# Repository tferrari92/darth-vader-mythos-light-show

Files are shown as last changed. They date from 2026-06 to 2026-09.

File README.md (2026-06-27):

# Darth Vader Mythos Light Show

An IR-remote-driven light-and-effects show for a Darth Vader Mythos statue, built on an
Arduino Uno. Each track on the remote triggers a choreographed routine synchronized to
music played from a DY-SV5W MP3 module.

The **basic build is 4 RGBW lamps + audio** — that's all you need to run the show. Three
extra effects are **optional** and toggled with feature flags (see
[Configuration](#configuration)): a NeoPixel front strip, smoke (humidifier + fan), and the
lightsaber. With every flag off, the sketch runs the lamps and audio standalone — it does
**not** wait for the ATtiny85 or touch any relays.

## Demo

- 🎥 **Video demo:** _TODO: YouTube link_
- 🖼️ **Build photos:** _TODO: link_

## Architecture

- **Master — Arduino Uno** ([`master/master.ino`](master/master.ino))
  - Drives **4× RGBW lamps** through a **PCA9685** 16-channel PWM driver, using the
    [MultiRGBWLeds](https://github.com/tferrari92/MultiRGBWLeds) library for the animations
    (crossfade, set, side-to-side, spin, flash). *(always on)*
  - Plays audio from a **DY-SV5W** MP3 module (SoftwareSerial). *(always on)*
  - Reads an **IR remote** to select tracks. *(always on)*
  - *Optional:* switches a **smoke** rig (humidifier relay + fan H-bridge) and a
    **lightsaber relay**.
  - *Optional:* sends I²C commands to the ATtiny85 front-strip slave:
    `0xAAAA` → fire animation, `0xBBBB` → blue animation.

- **Slave — ATtiny85** ([`attiny85/attiny85.ino`](attiny85/attiny85.ino)) *(optional — front strip)*
  - Drives a **55-LED WS2812B NeoPixel strip** with FastLED, running a Perlin-noise fire
    effect or a solid blue fill on command. Offloaded to its own MCU so the blocking LED
    timing doesn't disrupt the master's choreography.
  - [`FastLED_RGBW.h`](attiny85/FastLED_RGBW.h) adds RGBW support to FastLED
    (credit: Jim Bumgardner & David Madison).
  - Only needed if you enable the front strip; otherwise you can ignore the `attiny85/` sketch.

## Bill of materials

Build the **Basic** set first; add any of the optional modules later (each maps to a
[feature flag](#configuration)).

### Basic — 4 lamps + audio
- [Arduino Uno (or compatible)](https://a.co/d/03DOTip2)
- [PCA9685 16-channel PWM driver](https://a.co/d/0jiwvAFP)
- [4× RGBW LED lamps (common-anode)](https://a.co/d/08rguR4Z)
- [DY-SV5W Playback Module MP3 Board](https://a.co/d/0iwnKNiH) 
- [3.5mm Aux Cable](https://a.co/d/05ZY8Oyp)
- [Speaker (I used a Bose SoundLink Mini I)](https://a.co/d/0ehsrhri)
- [microSD card](https://a.co/d/0cLakK3m)
- [IR receiver + IR remote](https://a.co/d/0esAqea8)
- [12V powe supply](https://a.co/d/0cVwCTjt)
- [5V power supply](https://a.co/d/0ai2ccZ6)

#### Optional / Quality of life Items
  - [Lever Wire Connectors](https://a.co/d/073DuDCG)
  - [4x 5 Pin Magnetic Pogo Pin Connector](https://a.co/d/08rJCHPg)
  - [12V DC Male + Female Connector](https://a.co/d/08ywx2uR)
  - [USB Extensions Cable](https://a.co/d/0bbNSKzB)
  - [Matte Window Film](https://a.co/d/0bbNSKzB)

### Add-on — Front LED strip
- [Digispark ATtiny85](https://a.co/d/04rXa1Af)
- [3.28ft/1m 60 Pixel RGBW (Warm White) Led Strip](https://a.aliexpress.com/_m0XdlDt) — the sketch drives the first 55 pixels

### Add-on — Back smoke (LED + fan + humidifier)
- [5V Ultrasonic mist / humidifier module](https://a.aliexpress.com/_m0UEqIB)
- [5V L9110 Fan Motor Module](https://a.aliexpress.com/_msmvBKT) 
- LED — _TODO: AliExpress link_
- Relay module — _TODO: AliExpress link_

### Add-on — Lightsaber
- [3V 260mm White Led Filament](https://a.aliexpress.com/_mP3VffN)
- Transparent Acrylic Tube
- UV Resin
- Relay module — _TODO: AliExpress link_

## Wiring



The diagram shows the full wiring including all optional modules — wire only the sections for the modules you're building.

## Dependencies

Install via the Arduino IDE Library Manager (or "Add .ZIP Library"):

**Master (always required):**
- **[MultiRGBWLeds](https://github.com/tferrari92/MultiRGBWLeds)** — companion library for this project (RGBW lamp animations)
- **Adafruit PWM Servo Driver Library** — PCA9685 control
- **DYPlayerArduino** — DY-SV5W MP3 module
- **IRremote — version 3.x** ⚠️

> **Important: use IRremote 3.x, not 4.x.** This sketch uses IRremote's 3.x
> receive API. IRremote 4.x still *compiles* (via a deprecated compatibility
> shim) but **silently fails to decode** — buttons do nothing. In the Library
> Manager, pick a 3.x version (e.g. 3.9.0).

**ATtiny85 front strip (only if `ENABLE_FRONT_STRIP`):**
- **FastLED**

`SoftwareSerial` and `Wire` ship with the Arduino core.

## Configuration

Optional hardware is controlled by feature flags at the top of
[`master/master.ino`](master/master.ino). Arduino has no runtime env vars, so these are
compile-time toggles. They default to **off**, so the basic 4-lamp + audio build works
out of the box.

```cpp
#define ENABLE_FRONT_STRIP 0   // ATtiny85 NeoPixel front strip (I2C slave)
#define ENABLE_SMOKE       0   // Humidifier + fan
#define ENABLE_LIGHTSABER  0   // Lightsaber relay
```

Set a flag to `1` to enable that effect. The flags are wrapped in `#ifndef`, so you can also
override them at build time **without editing the file** (the closest thing to an "env var"):

```bash
# arduino-cli
arduino-cli compile --fqbn arduino:avr:uno master \
  --build-property "build.extra_flags=-DENABLE_SMOKE=1 -DENABLE_LIGHTSABER=1"
```

```ini
; platformio.ini
build_flags = -DENABLE_FRONT_STRIP=1 -DENABLE_SMOKE=1 -DENABLE_LIGHTSABER=1
```

Note: the lamp choreography is timed to the audio, so the small settle delays around the
front-strip commands are preserved even when the strip is disabled — the show stays in sync
in every configuration.

## Build & flash

1. Install the dependencies above.
2. (Optional) Set the [feature flags](#configuration) for any extra hardware you wired up.
3. **Master:** open [`master/master.ino`](master/master.ino), select **Arduino Uno**, upload.
4. **Slave (only if you enabled the front strip):** open
   [`attiny85/attiny85.ino`](attiny85/attiny85.ino), select the ATtiny85 via
   [ATTinyCore](https://github.com/SpenceKonde/ATTinyCore), upload.

## Controls

The IR remote maps each track to a routine (timed to the audio). Effects in *italics*
only fire if their feature flag is enabled. (Button codes are for the bundled NEC remote;
if yours differs, read the HEX over Serial at 9600 and update the cases in `master.ino`.)

| Button | Action |
|---|---|
| **1** | **I Did – Original** |
| **2** | **I Did – Cumbia** |
| **3** | **I Did – Lofi** |
| **4** | **I Did – Metal**  |
| **5** | **For Whom The Bell Tolls** |
| **Power** | Toggle the always-on ambient scene |

## Enclosure

3D-printable enclosure that holds everything together — the STL lives at
[`enclosure/enclosure.stl`](enclosure/enclosure.stl).

## Audio

The audio files live on the DY-SV5W's **microSD card**, numbered in track order:

- `0001 - I Did (Original).mp3`
- `0002 - I Did (Cumbia).mp3`
- `0003 - I Did (Lofi).mp3`
- `0004 - I Did (Metal).mp3`
- `0005 - For Whom The Bell Tolls.mp3` (Epic hallway scene from Rogue One)
- `0006 - KeepAlive.wav` — a low, looping keep-alive tone that plays whenever nothing else is,
  so the audio amp never sees silence and never auto-sleeps

They are **not** committed to this repo.

- ⬇️ [**Download tracks**](https://drive.google.com/drive/folders/14aJys-XmJGN54O0cnzooF6nU0tt411FF?usp=sharing)

## License

[MIT](LICENSE) © Tomas Ferrari

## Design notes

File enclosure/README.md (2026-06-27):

# Enclosure

3D-printable enclosure that houses the electronics for the Darth Vader Mythos light show.

Use this as a rough sketch. Specific meausurements may vary depending on your requirements. But I suggest not going under 120cm x 45cm x 12cm.

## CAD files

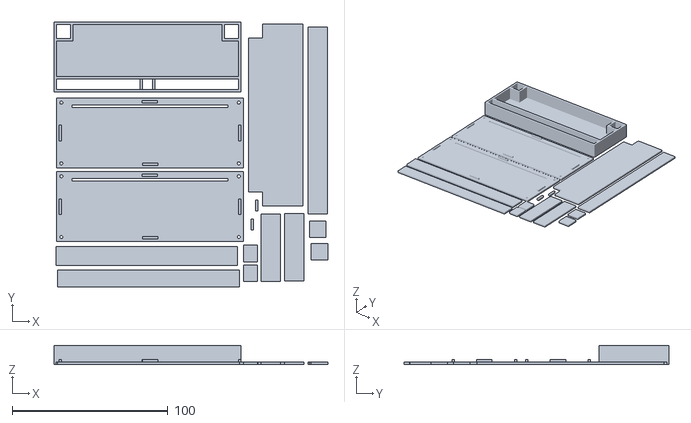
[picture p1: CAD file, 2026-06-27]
enclosure/enclosure.stl
176.0 x 170.0 x 12.4

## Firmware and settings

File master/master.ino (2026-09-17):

#include <Arduino.h>
#include "SoftwareSerial.h"
#include "Wire.h"
#include <MultiRGBWLeds.h>
#include "DYPlayerArduino.h"
#include "IRremote.h"

// ============================================================
//  FEATURE FLAGS
//  ------------------------------------------------------------
//  The basic build is 4 RGBW lamps + audio, which works with
//  every flag below set to 0. Turn on the extra hardware you
//  actually wired up by setting its flag to 1.
//
//  You can either edit the defaults here, OR override them at
//  build time without touching this file (the closest thing to
//  an "env var" on Arduino), e.g. with arduino-cli:
//    --build-property "build.extra_flags=-DENABLE_SMOKE=1"
//  or in platformio.ini:
//    build_flags = -DENABLE_SMOKE=1
// ============================================================
#ifndef ENABLE_FRONT_STRIP
#define ENABLE_FRONT_STRIP 0 // ATtiny85 NeoPixel front strip (I2C slave)
#endif
#ifndef ENABLE_SMOKE
#define ENABLE_SMOKE 0 // Humidifier + fan
#endif
#ifndef ENABLE_LIGHTSABER
#define ENABLE_LIGHTSABER 0 // Lightsaber relay
#endif

// RGBW lamps -- the MultiRGBWLeds library owns the PCA9685 (default 0x40).
MultiRGBWLeds leds;

// MP3 Player -- always required for audio
SoftwareSerial mySerial(3, 11); // RX, TX (MP3 Player)
const int volume = 25;          // Volume level
DY::Player player(&mySerial);

// IR Receiver -- always required
const int receiver = 13;          // Signal Pin of IR receiver to Arduino Digital Pin 13
IRrecv irrecv(receiver);          // Create instance of 'irrecv'
bool ambientOn = false;               // Power button toggles the static ambient scene
unsigned long lastPressMs = 0;        // millis() of the last accepted IR press
const unsigned long debounceMs = 500; // ignore repeat presses within this window

// Audio amp keep-alive: a low, looping tone (track 6 on the SD) plays whenever
// nothing else is, so the amp never sees silence and never auto-sleeps.
const int keepAliveTrack = 6;
unsigned long lastKeepAliveMs = 0;
const unsigned long keepAliveCheckMs = 1000; // how often to re-check play state

// ATtiny I2C Slave Address (front strip)
#define slaveAddress 0x23

// Relay (Humidifier) -- smoke
const int humedifierRelay = 7;

// Relay (Lightsaber)
const int lighsaberRelay = 8;

// Fan -- smoke
const int fanInA = 9;
const int fanInB = 10;
const int speed = 120;

// ------------------------------------------------------------
//  Optional-hardware wrappers
//  These no-op when their feature is disabled, so the show
//  functions below stay readable and the #if guards live here.
// ------------------------------------------------------------

// Send a command to the ATtiny front-strip slave.
// The original protocol included a 500ms settle delay that the
// show timings are tuned around -- we keep it even when the strip
// is disabled so the lamp choreography stays in sync with the audio.
void frontStripSend(uint16_t command)
{
#if ENABLE_FRONT_STRIP
    Wire.beginTransmission(slaveAddress);
    Wire.write(highByte(command));
    Wire.write(lowByte(command));
    Wire.endTransmission();
    Serial.print("Sent command: 0x");
    Serial.println(command, HEX);

    delay(500); // Allow time for the slave to process

    // Request confirmation from ATtiny
    Wire.requestFrom(slaveAddress, 1);
    if (Wire.available())
    {
        byte confirmation = Wire.read();
        Serial.print("Confirmation: 0x");
        Serial.println(confirmation, HEX);
    }
#else
    (void)command;
    delay(500); // Keep choreography in sync with the audio
#endif
}

// Smoke = humidifier + fan, switched on/off together.
void smokeOn()
{
#if ENABLE_SMOKE
    // Turn fan ON
    analogWrite(fanInA, speed); // PWM Speed. 255 is full speed
    digitalWrite(fanInB, LOW);  // Direction
    // Activate humidifier
    digitalWrite(humedifierRelay, HIGH);
#endif
}

void smokeOff()
{
#if ENABLE_SMOKE
    digitalWrite(humedifierRelay, LOW);
    // Turn fan OFF
    digitalWrite(fanInA, LOW);
    digitalWrite(fanInB, LOW);
#endif
}

void saberOn()
{
#if ENABLE_LIGHTSABER
    digitalWrite(lighsaberRelay, HIGH);
#endif
}

void saberOff()
{
#if ENABLE_LIGHTSABER
    digitalWrite(lighsaberRelay, LOW);
#endif
}

// ------------------------------------------------------------
//  Ambient scene
//  The calm resting state the rig falls back to. The Power button
//  snaps to it; finished shows fade up into it.
// ------------------------------------------------------------

// Snap straight to the ambient scene (used by the Power toggle).
void setAmbient()
{
    leds.set(
        LampPosition::FrontLeft, LampColor::White, 1,
        LampPosition::BackLeft, LampColor::Orange, 5,
        LampPosition::FrontRight, LampColor::White, 10,
        LampPosition::BackRight, LampColor::Red, 2);
    ambientOn = true;
}

// Fade up into the ambient scene from dark over durationMs.
void fadeToAmbient(uint16_t durationMs)
{
    leds.resetAllPositions(); // known starting point (off) so the fade is clean
    leds.crossFade(
        LampPosition::FrontLeft, LampColor::White, 0, LampColor::White, 1,
        LampPosition::BackLeft, LampColor::Orange, 0, LampColor::Orange, 5,
        LampPosition::FrontRight, LampColor::White, 0, LampColor::White, 10,
        LampPosition::BackRight, LampColor::Red, 0, LampColor::Red, 2,
        durationMs);
    ambientOn = true;
}

// Called when a light show finishes: hold for a couple of seconds,
// then gently drift back into the ambient scene.
void returnToAmbient()
{
    leds.resetAllPositions(); // clear whatever the show left lit
    delay(500);              // a couple of seconds of darkness after the show
    fadeToAmbient(3000);      // gentle fade-in
}

void setup()
{
    // Terminal
    Serial.begin(9600);

    // MP3 Player
    player.begin();
    player.setVolume(volume);

    // IR Receiver
    irrecv.enableIRIn(); // Start the receiver

    // RGBW lamps. begin() creates/configures the PCA9685 and calls Wire.begin().
    // Each lamp is four PCA9685 channels (0-15) in {R, G, B, W} order.
    const uint8_t backLeft[4] = {4, 5, 6, 7};
    const uint8_t frontLeft[4] = {0, 1, 2, 3};
    const uint8_t frontRight[4] = {12, 13, 14, 15};
    const uint8_t backRight[4] = {8, 9, 10, 11};
    leds.begin(backLeft, frontLeft, frontRight, backRight);

#if ENABLE_SMOKE
    // Relay (Humidifier) + Fan
    pinMode(humedifierRelay, OUTPUT);
    pinMode(fanInA, OUTPUT);
    pinMode(fanInB, OUTPUT);
#endif

#if ENABLE_LIGHTSABER
    // Relay (Lightsaber)
    pinMode(lighsaberRelay, OUTPUT);
#endif

#if ENABLE_FRONT_STRIP
    // Check if ATtiny slave is available. Keep retrying until it is found.
    while (true)
    {
        Wire.beginTransmission(slaveAddress);
        byte busStatus = Wire.endTransmission();

        if (busStatus == 0)
        {
            Serial.println("Slave found.");
            break; // Exit the loop and continue execution
        }

        Serial.println("Slave not found. Retrying...");
        delay(1000); // Wait 1 second before retrying
    }
#endif

    // Power-on default: rig rests in the ambient scene.
    returnToAmbient(); 
    setAmbient();
}

void loop()
{
    // Keep the audio amp awake. If nothing is playing, (re)start the looping
    // keep-alive tone. Throttled so we don't spam the DFPlayer over serial.
    unsigned long tNow = millis();
    if (tNow - lastKeepAliveMs >= keepAliveCheckMs)
    {
        lastKeepAliveMs = tNow;
        if (player.checkPlayState() == DY::PlayState::Stopped)
        {
            player.playSpecified(keepAliveTrack);
        }
    }

    if (irrecv.decode())
    { // Have we received an IR signal?
        unsigned long now = millis();
        uint32_t code = irrecv.decodedIRData.decodedRawData;
        bool isRepeat = irrecv.decodedIRData.flags & IRDATA_FLAGS_IS_REPEAT;

        // Guardrail: ignore NEC repeat frames (button held) and any press within
        // the debounce window. Stops one physical press being read twice, which
        // made the Power toggle flicker on/off.
        if (isRepeat || code == 0 || (now - lastPressMs) < debounceMs)
        {
            irrecv.resume();
            return;
        }
        lastPressMs = now;

        Serial.print("Button HEX: 0x");
        Serial.println(code, HEX);

        switch (code)
        {

            // BUTTON HEX CODES:
            // Power              0xBA45FF00
            // VOL+               0xB946FF00
            // FUNC/STOP          0xB847FF00
            // |<< (Rewind)       0xBB44FF00
            // >|| (Play/Pause)   0xBF40FF00
            // >>| (Fast Forward) 0xBC43FF00
            // Arrow Down         0xF807FF00
            // VOL-               0xEA15FF00
            // Arrow Up           0xF609FF00
            // 0                  0xE916FF00
            // EQ                 0xE619FF00
            // ST/REPT            0xF20DFF00
            // 1                  0xF30CFF00
            // 2                  0xE718FF00
            // 3                  0xA15EFF00
            // 4                  0xF708FF00
            // 5                  0xE31CFF00
            // 6                  0xA55AFF00
            // 7                  0xBD42FF00
            // 8                  0xAD52FF00
            // 9                  0xB54AFF00

        case 0xBA45FF00: // Power button -- toggle static ambient scene (no audio, no animation)
            ambientOn = !ambientOn;
            if (ambientOn)
            {
                Serial.println("Ambient ON");
                setAmbient();
            }
            else
            {
                Serial.println("Ambient OFF");
                leds.resetAllPositions();
            }
            break;

        case 0xF30CFF00: // Button 1 pressed
            Serial.println("Playing: 'I Did - Original'");
            player.playSpecified(1);
            iDidOriginal();
            returnToAmbient();
            break;

        case 0xE718FF00: // Button 2 pressed
            Serial.println("Playing: 'I Did - Cumbia'");
            player.playSpecified(2);
            iDidCumbia();
            returnToAmbient();
            break;

        case 0xA15EFF00: // Button 3 pressed
            Serial.println("Playing: 'I Did - Lofi'");
            player.playSpecified(3);
            iDidLofi();
            returnToAmbient();
            break;

        case 0xF708FF00: // Button 4 pressed
            Serial.println("Playing: 'I Did - Metal'");
            player.playSpecified(4);
            iDidMetal();
            returnToAmbient();
            break;

        case 0xE31CFF00: // Button 5 pressed
            Serial.println("Playing: 'For Whom The Bell Tolls'");
            player.playSpecified(5);
            forWhomTheBellTolls();
            returnToAmbient();
            break;
        }

        irrecv.resume(); // Receive the next value
    }
}

void iDidOriginal()
{
    iDidIntro();

    smokeOn();
    saberOn();

    leds.set(
        LampPosition::BackLeft, LampColor::Orange, 10,
        LampPosition::FrontLeft, LampColor::Red, 3,
        LampPosition::FrontRight, LampColor::White, 6,
        LampPosition::BackRight, LampColor::Red, 10);

    frontStripSend(0xAAAA); // Has a 500ms delay (kept for audio sync)... + 0.5 = 17.5

    delay(1800); // + 1.8 = 19.3

    leds.crossFade(
        LampPosition::BackLeft, LampColor::Orange, 10, LampColor::Orange, 3,
        LampPosition::FrontLeft, LampColor::Red, 3, LampColor::Red, 1,
        LampPosition::FrontRight, LampColor::White, 6, LampColor::White, 1,
        LampPosition::BackRight, LampColor::Red, 10, LampColor::Red, 3,
        5500);

    leds.set(
        LampPosition::BackLeft, LampColor::Orange, 10,
        LampPosition::FrontLeft, LampColor::Red, 3,
        LampPosition::FrontRight, LampColor::White, 6,
        LampPosition::BackRight, LampColor::Red, 10);

    delay(5900); // + 5.9 = 30.7

    leds.crossFade(
        LampPosition::BackLeft, LampColor::Orange, 10, LampColor::Orange, 0,
        LampPosition::FrontLeft, LampColor::Red, 3, LampColor::Red, 0,
        LampPosition::FrontRight, LampColor::White, 6, LampColor::White, 0,
        LampPosition::BackRight, LampColor::Red, 10, LampColor::Red, 0,
        3000);

    smokeOff();
    saberOff();

    delay(3000);
}

void iDidCumbia()
{
    iDidIntro();

    smokeOn();
    saberOn();

    // La primera vuelta de sideToSide la hacemos manual apra poder meter el frontStripSend en el medio

    ////////////////////////////////////////////////////////////////////////
    // Arranca la cumbia bebeeeeee
    leds.set(
        LampPosition::BackLeft, LampColor::Green, 10,
        LampPosition::FrontLeft, LampColor::Green, 10,
        LampPosition::FrontRight, LampColor::Indigo, 10,
        LampPosition::BackRight, LampColor::Indigo, 10);

    frontStripSend(0xBBBB); // Has a 500ms delay (kept for audio sync)

    delay(164);

    leds.set(
        LampPosition::BackLeft, LampColor::Indigo, 10,
        LampPosition::FrontLeft, LampColor::Indigo, 10,
        LampPosition::FrontRight, LampColor::Green, 10,
        LampPosition::BackRight, LampColor::Green, 10);

    delay(664);

    leds.sideToSide(Axis::LeftRight, LampColor::Green, LampColor::Indigo, 664, 3); // axis, color1, color2, halfPeriodMs, cycles
    leds.sideToSide(Axis::LeftRight, LampColor::Sky, LampColor::Pink, 664, 4);    // axis, color1, color2, halfPeriodMs, cycles

    cuaaCuCuCuaaCuCuCuararaCuCuaaCuCuCuararaCuCuaaCuCuCuaaCuuCuCuaa();
    cuaaCuCuCuaaCuCuCuararaCuCuaaCuCuCuararaCuCuaaCuCuCuaaCuuCuCuaa();
    cuaaCuCuCuaaCuCuCuararaCuCuaaCuCuCuararaCuCuaaCuCuCuaaCuuCuCuaa();

    paaPaaPaaPaaPaPaaPaaPaPaaPeePeePeePeePePeePeePePee();

    cuaaCuCuCuaaCuCuCuararaCuCuaaCuCuCuararaCuCuaaCuCuCuaaCuuCuCuaa();
    cuaaCuCuCuaaCuCuCuararaCuCuaaCuCuCuararaCuCuaaCuCuCuaaCuuCuCuaa();

    leds.crossFade(
        LampPosition::BackLeft, LampColor::Red, 10, LampColor::Red, 0,
        LampPosition::FrontLeft, LampColor::Red, 10, LampColor::Red, 0,
        LampPosition::FrontRight, LampColor::Red, 10, LampColor::Red, 0,
        LampPosition::BackRight, LampColor::Red, 10, LampColor::Red, 0,
        8000);

    smokeOff();
    saberOff();
}

void iDidLofi()
{
    iDidIntro();

    leds.set(
        LampPosition::BackLeft, LampColor::Indigo, 10,
        LampPosition::FrontLeft, LampColor::Indigo, 10,
        LampPosition::FrontRight, LampColor::Magenta, 10,
        LampPosition::BackRight, LampColor::Magenta, 10);

    frontStripSend(0xBBBB); // Has a 500ms delay (kept for audio sync)... + 0.5 = 17.5
}

void iDidMetal()
{
    iDidIntro();

    leds.set(
        LampPosition::BackLeft, LampColor::Orange, 10,
        LampPosition::FrontLeft, LampColor::Orange, 10,
        LampPosition::FrontRight, LampColor::Red, 10,
        LampPosition::BackRight, LampColor::Red, 10);

    frontStripSend(0xAAAA); // Has a 500ms delay (kept for audio sync)... + 0.5 = 17.5
}

void forWhomTheBellTolls()
{
    delay(23300);
    leds.crossFade(
        LampPosition::BackLeft, LampColor::Red, 0, LampColor::Red, 10,
        LampPosition::FrontLeft, LampColor::Red, 0, LampColor::Red, 10,
        LampPosition::FrontRight, LampColor::Red, 0, LampColor::Red, 10,
        LampPosition::BackRight, LampColor::Red, 0, LampColor::Red, 10,
        100);
}

void iDidIntro()
{
    leds.resetAllPositions();
    delay(1200); // + 1.2

    //////////////////////////////////////////
    // Up to here we MUST sum 1.2 seconds!!!
    leds.crossFade(
        LampPosition::FrontLeft, LampColor::Sky, 0, LampColor::Sky, 10,
        LampPosition::FrontRight, LampColor::White, 0, LampColor::White, 10,
        8000);

    leds.crossFade(
        LampPosition::FrontLeft, LampColor::Sky, 10, LampColor::Sky, 0,
        LampPosition::FrontRight, LampColor::White, 10, LampColor::White, 0,
        4500);

    //////////////////////////////////////////
    // Up to here we MUST sum 13.7 seconds!!!
    delay(3300); // + 3.3 = 17
}

void paaPaaPaaPaaPaPaaPaaPaPaaPeePeePeePeePePeePeePePee()
{
    leds.sideToSide(Axis::LeftRight, LampColor::Green, LampColor::Indigo, 664, 4); // axis, color1, color2, halfPeriodMs, cycles
    leds.sideToSide(Axis::LeftRight, LampColor::Sky, LampColor::Pink, 664, 4);    // axis, color1, color2, halfPeriodMs, cycles
}

void cuaaCuCuCuaaCuCuCuararaCuCuaaCuCuCuararaCuCuaaCuCuCuaaCuuCuCuaa()
{

    // cuaaa1
    leds.crossFade(
        LampPosition::BackLeft, LampColor::Red, 0, LampColor::Red, 10,
        LampPosition::FrontLeft, LampColor::Red, 0, LampColor::Red, 10,
        LampPosition::FrontRight, LampColor::Red, 0, LampColor::Red, 10,
        LampPosition::BackRight, LampColor::Red, 0, LampColor::Red, 10,
        400);

    delay(270);

    leds.resetAllPositions();

    // cucu2.1
    leds.flash(
        LampPosition::BackLeft, LampColor::Orange, 10,
        LampPosition::BackRight, LampColor::Orange, 10,
        200, 100);
        
        // cucu2.2
        leds.flash(
        LampPosition::FrontRight, LampColor::Yellow, 10,
        LampPosition::FrontLeft, LampColor::Yellow, 10,
        200, 100);

    // cuaaa3
    leds.crossFade(
        LampPosition::BackLeft, LampColor::Red, 0, LampColor::Red, 10,
        LampPosition::FrontLeft, LampColor::Red, 0, LampColor::Red, 10,
        LampPosition::FrontRight, LampColor::Red, 0, LampColor::Red, 10,
        LampPosition::BackRight, LampColor::Red, 0, LampColor::Red, 10,
        400);

    delay(270);

    leds.resetAllPositions();

    // cucu4.1
    leds.flash(
        LampPosition::FrontRight, LampColor::Yellow, 10,
        LampPosition::BackRight, LampColor::Yellow, 10,
        200, 100);

    // cucu4.2
    leds.flash(
        LampPosition::BackLeft, LampColor::Yellow, 10,
        LampPosition::FrontLeft, LampColor::Yellow, 10,
        200, 100);

    // cuarara5
    leds.spin(LampColor::Aqua, Direction::Clockwise, 90, 2); // color, direction, stepMs, rotations
    leds.resetAllPositions();

    delay(200);

    // cucuaa6.1
    leds.flash(
        LampPosition::FrontRight, LampColor::Yellow, 10,
        LampPosition::BackRight, LampColor::Yellow, 10,
        200, 100);

    // cucuaa6.2
    leds.crossFade(
        LampPosition::BackLeft, LampColor::Red, 0, LampColor::Red, 10,
        LampPosition::FrontLeft, LampColor::Red, 0, LampColor::Red, 10,
        LampPosition::FrontRight, LampColor::Red, 0, LampColor::Red, 10,
        LampPosition::BackRight, LampColor::Red, 0, LampColor::Red, 10,
        400);

    delay(350);

    leds.resetAllPositions();

    // cucu7.1
    leds.flash(
        LampPosition::FrontRight, LampColor::Yellow, 10,
        LampPosition::BackRight, LampColor::Yellow, 10,
        200, 100);

    // cucu7.2
    leds.flash(
        LampPosition::BackLeft, LampColor::Yellow, 10,
        LampPosition::FrontLeft, LampColor::Yellow, 10,
        200, 100);

    // cuarara8
    leds.spin(LampColor::Orange, Direction::Anticlockwise, 90, 2); // color, direction, stepMs, rotations
    leds.resetAllPositions();

    delay(200);

    // cucuaa9.1
    leds.flash(
        LampPosition::FrontRight, LampColor::Yellow, 10,
        LampPosition::BackRight, LampColor::Yellow, 10,
        200, 100);

    // cucuaa9.2
    leds.crossFade(
        LampPosition::BackLeft, LampColor::Red, 0, LampColor::Red, 10,
        LampPosition::FrontLeft, LampColor::Red, 0, LampColor::Red, 10,
        LampPosition::FrontRight, LampColor::Red, 0, LampColor::Red, 10,
        LampPosition::BackRight, LampColor::Red, 0, LampColor::Red, 10,
        400);

    delay(300);

    leds.resetAllPositions();

    // cuuucu10.1
    leds.set(
        LampPosition::BackRight, LampColor::Yellow, 10,
        LampPosition::BackLeft, LampColor::Yellow, 10);
    delay(300);

    // cuuucu10.2
    leds.set(
        LampPosition::FrontLeft, LampColor::Yellow, 10,
        LampPosition::FrontRight, LampColor::Yellow, 10);
    delay(300);

    // cuaaa11
    leds.crossFade(
        LampPosition::BackLeft, LampColor::Red, 0, LampColor::Red, 10,
        LampPosition::FrontLeft, LampColor::Red, 0, LampColor::Red, 10,
        LampPosition::FrontRight, LampColor::Red, 0, LampColor::Red, 10,
        LampPosition::BackRight, LampColor::Red, 0, LampColor::Red, 10,
        400);

    delay(300);

    leds.resetAllPositions();

    // cuuucu12.1
    leds.set(
        LampPosition::BackRight, LampColor::Yellow, 10,
        LampPosition::BackLeft, LampColor::Yellow, 10);
    delay(400);

    // cuuucu12.2
    leds.set(
        LampPosition::FrontLeft, LampColor::Yellow, 10,
        LampPosition::FrontRight, LampColor::Yellow, 10);
    delay(300);

    // cuaaaaaa13
    leds.crossFade(
        LampPosition::BackLeft, LampColor::Red, 0, LampColor::Red, 10,
        LampPosition::FrontLeft, LampColor::Red, 0, LampColor::Red, 10,
        LampPosition::FrontRight, LampColor::Red, 0, LampColor::Red, 10,
        LampPosition::BackRight, LampColor::Red, 0, LampColor::Red, 10,
        500);

    delay(800);
}

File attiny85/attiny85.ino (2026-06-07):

#include <Wire.h>
#include "FastLED.h"
#include "FastLED_RGBW.h"

#define slaveAddress 0x23
#define NUM_LEDS 55
#define DATA_PIN 3
#define BRIGHTNESS 255 // 0 to 255

// WHAT WAS THIS FOR??
// #define led 1

//////////////////////////////////////////////////////
// DEBUG CODE: Uncomment to test using the onboard LED
// volatile int blinkCount = 0;

//////////////////////////////////////////////////////
// DEBUG CODE: Uncomment to send confirmation to Master
// volatile byte responseCode = 0;

volatile bool fireAnimation = false; // Flag to control fire animation
volatile bool blueAnimation = false; // New flag for blue animation

unsigned long fireStartTime = 0;          // Track fire animation start
unsigned long blueStartTime = 0;          // Track blue animation start
const unsigned long fireDuration = 16700; // Fire duration (16.7 seconds)
const unsigned long blueDuration = 87000; // Blue duration (90 seconds)

CRGBW leds[NUM_LEDS];
CRGB *ledsRGB = (CRGB *)&leds[0];

//////////////////////////////////////////////////////
// Colors and palettes:
// https://fastled.io/docs/group___predefined_palettes.html#ga8932790994cfe78cf535fce88502d649
// https://github.com/FastLED/FastLED/wiki/Pixel-reference
//
// Examples:
// LavaColors_p is:
// {
//     CRGB::Black,
//     CRGB::Maroon,
//     CRGB::Black,
//     CRGB::Maroon,

//     CRGB::DarkRed,
//     CRGB::DarkRed,
//     CRGB::Maroon,
//     CRGB::DarkRed,

//     CRGB::DarkRed,
//     CRGB::DarkRed,
//     CRGB::Red,
//     CRGB::Orange,

//     CRGB::White,
//     CRGB::Orange,
//     CRGB::Red,
//     CRGB::DarkRed
// }

// OceanColors_p is:
// {
//     CRGB::MidnightBlue,
//     CRGB::DarkBlue,
//     CRGB::MidnightBlue,
//     CRGB::Navy,

//     CRGB::DarkBlue,
//     CRGB::MediumBlue,
//     CRGB::SeaGreen,
//     CRGB::Teal,

//     CRGB::CadetBlue,
//     CRGB::Blue,
//     CRGB::DarkCyan,
//     CRGB::CornflowerBlue,

//     CRGB::Aquamarine,
//     CRGB::SeaGreen,
//     CRGB::Aqua,
//     CRGB::LightSkyBlue
// }

// If you want to create a custom palette, you can do it like this:
// Define a custom color palette with 16 colors
const TProgmemRGBPalette16 customPalette PROGMEM = {
    CRGB::DarkRed, CRGB::DarkRed, CRGB::DarkRed, CRGB::Maroon,
    CRGB::Maroon, CRGB::OrangeRed, CRGB::Maroon, CRGB::OrangeRed,
    CRGB::Maroon, CRGB::OrangeRed, CRGB::Red, CRGB::DarkRed,
    CRGB::Maroon, CRGB::Orange, CRGB::Red, CRGB::OrangeRed};

const uint8_t brightnessScale = 150; // Scaling factor for brightness noise
const uint8_t indexScale = 100;      // Scaling factor for color index noise

void setup()
{
  Wire.begin(slaveAddress);
  Wire.onReceive(receiveEvent);

  //////////////////////////////////////////////////////
  // DEBUG CODE: Uncomment to send confirmation to Master
  // Wire.onRequest(sendEvent);

  // WHAT WAS THIS FOR??
  // pinMode(led, OUTPUT);

  FastLED.addLeds<WS2812B, DATA_PIN, RGB>(ledsRGB, getRGBWsize(NUM_LEDS));

  FastLED.setBrightness(BRIGHTNESS);
  FastLED.show();
}

void loop()
{
  unsigned long currentTime = millis();

  // Handle fire animation
  if (fireAnimation)
  {
    if (currentTime - fireStartTime < fireDuration)
    {
      runFire();
      FastLED.show();
    }
    else
    {
      fireAnimation = false;
      FastLED.clear();
      FastLED.show();
    }
  }
  // Handle blue animation
  else if (blueAnimation)
  {
    if (currentTime - blueStartTime >= blueDuration)
    {
      blueAnimation = false;
      FastLED.clear();
      FastLED.show();
    }
  }
  //////////////////////////////////////////////////////
  // DEBUG CODE: Uncomment to test using the onboard LED
  // if (blinkCount > 0)
  // {
  //   for (int i = 0; i < blinkCount; i++)
  //   {
  //     digitalWrite(led, HIGH);
  //     delay(250);
  //     digitalWrite(led, LOW);
  //     delay(250);
  //   }
  //   blinkCount = 0; // Reset after blinking
  // }
}

void receiveEvent(int howMany)
{
  int receivedData = Wire.read() << 8 | Wire.read();

  if (receivedData == 0xAAAA)
  {
    //////////////////////////////////////////////////////
    // DEBUG CODE: Uncomment to test using the onboard LED
    // blinkCount = 1;      // Blink once

    //////////////////////////////////////////////////////
    // DEBUG CODE: Uncomment to send confirmation to Master
    // responseCode = 0x11;           // Confirmation for 0xAAAA

    fireAnimation = true;
    fireStartTime = millis();
  }
  else if (receivedData == 0xBBBB)
  {
    //////////////////////////////////////////////////////
    // DEBUG CODE: Uncomment to test using the onboard LED
    // blinkCount = 3;      // Blink three times

    //////////////////////////////////////////////////////
    // DEBUG CODE: Uncomment to send confirmation to Master
    // responseCode = 0x22;   // Confirmation for 0xBBBB
    blueAnimation = true;
    blueStartTime = millis();
    colorFill(CRGB::Blue);
    FastLED.show();
  }
}

//////////////////////////////////////////////////////
// DEBUG CODE: Uncomment to send confirmation to Master
// void sendEvent()
// {
//   Wire.write(responseCode); // Send confirmation to Master
// }

void colorFill(CRGB c)
{
  for (int i = 0; i < NUM_LEDS; i++)
  {
    leds[i] = c;
  }
}

void runFire()
{
  // Loop through each LED in the strip
  for (int i = 0; i < NUM_LEDS; i++)
  {
    // Generate a noise-based brightness value for the current LED
    uint8_t brightness = inoise8(i * brightnessScale, millis() / 5);

    // Generate a noise-based color index for the current LED
    uint8_t index = inoise8(i * indexScale, millis() / 10);

    // Set the color of the current LED using the custom palette, index, and brightness
    leds[i] = ColorFromPalette(customPalette, index, brightness);

    // Alternative: Use a predefined palette like "LavaColors_p"
    // leds[i] = ColorFromPalette(LavaColors_p, index, brightness);
  }
}

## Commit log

2026-06-07 Initial commit: Darth Vader Mythos light show firmware
    Master (Arduino Uno) + ATtiny85 slave sketches for an IR-driven
    light-and-effects show. Uses the MultiRGBWLeds library.
2026-06-07 Make front strip, smoke, and lightsaber optional via feature flags
    The basic build is now just 4 RGBW lamps + audio. Optional hardware
    (ATtiny85 front strip, humidifier+fan smoke, lightsaber relay) is gated
    behind ENABLE_FRONT_STRIP / ENABLE_SMOKE / ENABLE_LIGHTSABER compile-time
    flags, defaulting to off. Flags use #ifndef so they can be overridden by
    build flags (e.g. -DENABLE_SMOKE=1) without editing the sketch.
    Notably, the setup() loop that blocked forever waiting for the ATtiny
    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
2026-06-07 Update master sketch to MultiRGBWLeds v2 API
    - Use an instance (`leds`) that owns the PCA9685; removed the sketch's
    own Adafruit_PWMServoDriver global and the manual Wire/driver setup.
    - Scoped enums (LampPosition::/LampColor::/Axis::/Direction::).
    - Brightness migrated from the old 0-10 scale to 0-255 (10->255, 3->77).
2026-06-07 Use MultiRGBWLeds Calibrated mode (0-10 brightness)
    The library now defaults to Calibrated color mode (0-10 brightness),
    which reproduces the original tuned hues. Revert the lamp brightness
    values from the temporary 0-255 scale back to 0-10 (255->10, 77->3).
    [master.ino]
2026-06-08 Document IRremote 3.x requirement
    IRremote 4.x compiles via a legacy shim but silently fails to decode at
    runtime (buttons do nothing). Confirmed on hardware; 3.x works. Flag the
    version requirement prominently in the dependencies.
2026-06-12 fix wiring
2026-06-27 add enclosure
    [enclosure.stl]
